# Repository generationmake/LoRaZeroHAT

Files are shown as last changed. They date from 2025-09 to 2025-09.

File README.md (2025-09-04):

# LoRaZeroHAT
Raspberry Pi HAT with Ai-Thinker Ra-01 or Ra-02 LoRa module connected via SPI and an u-blox NEO-6M or NEO-M8N GNSS receiver connected to serial.

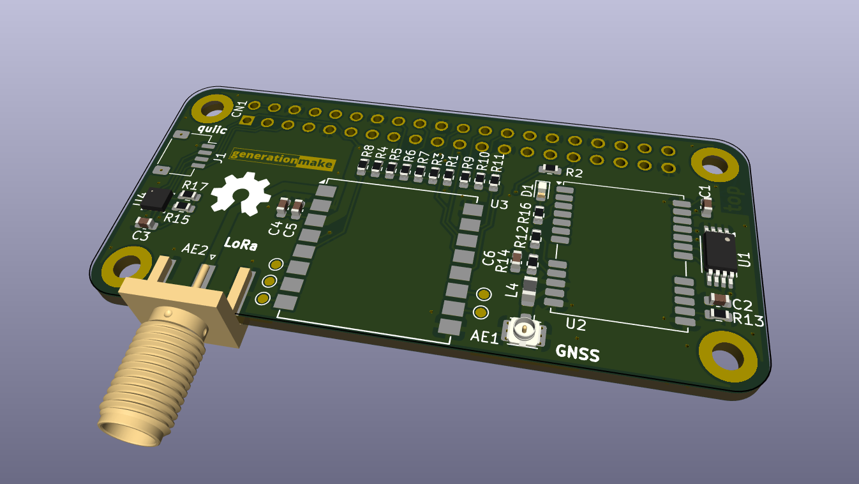
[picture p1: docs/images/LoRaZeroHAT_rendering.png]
LoRaZeroHAT rendering


## PCB

### Top

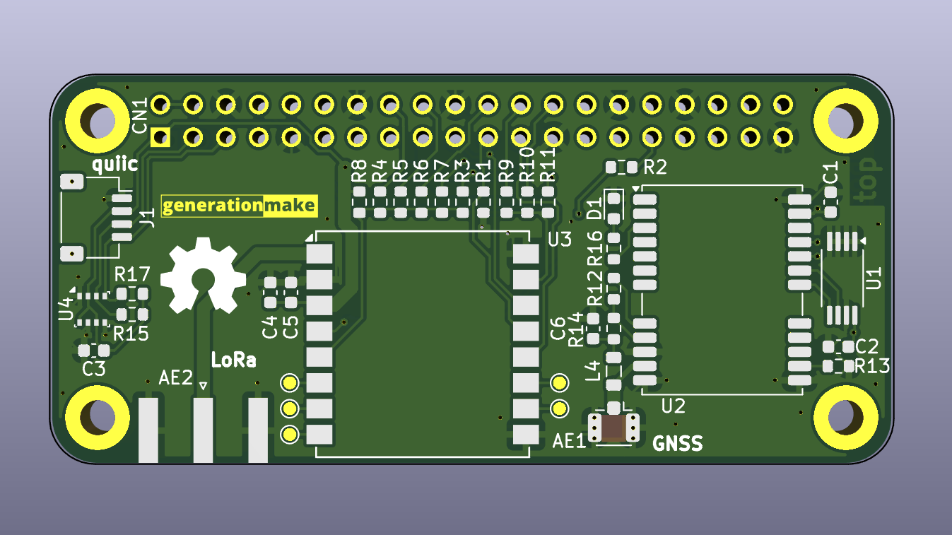
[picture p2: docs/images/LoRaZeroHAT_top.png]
LoRaZeroHAT PCB top


### Bottom

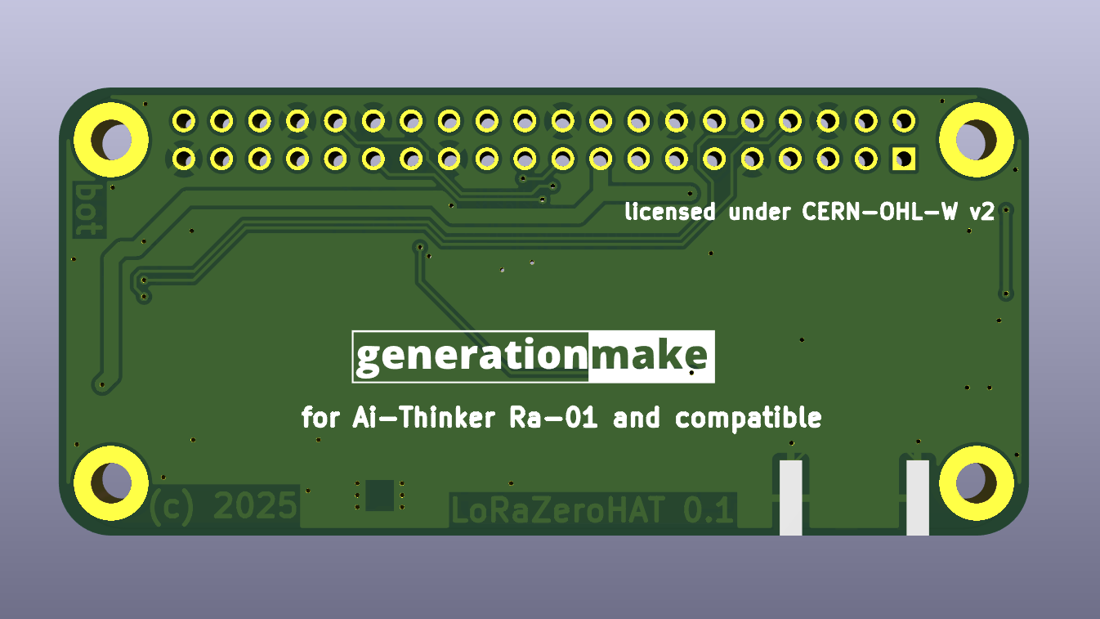
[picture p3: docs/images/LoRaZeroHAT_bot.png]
LoRaZeroHAT PCB bot


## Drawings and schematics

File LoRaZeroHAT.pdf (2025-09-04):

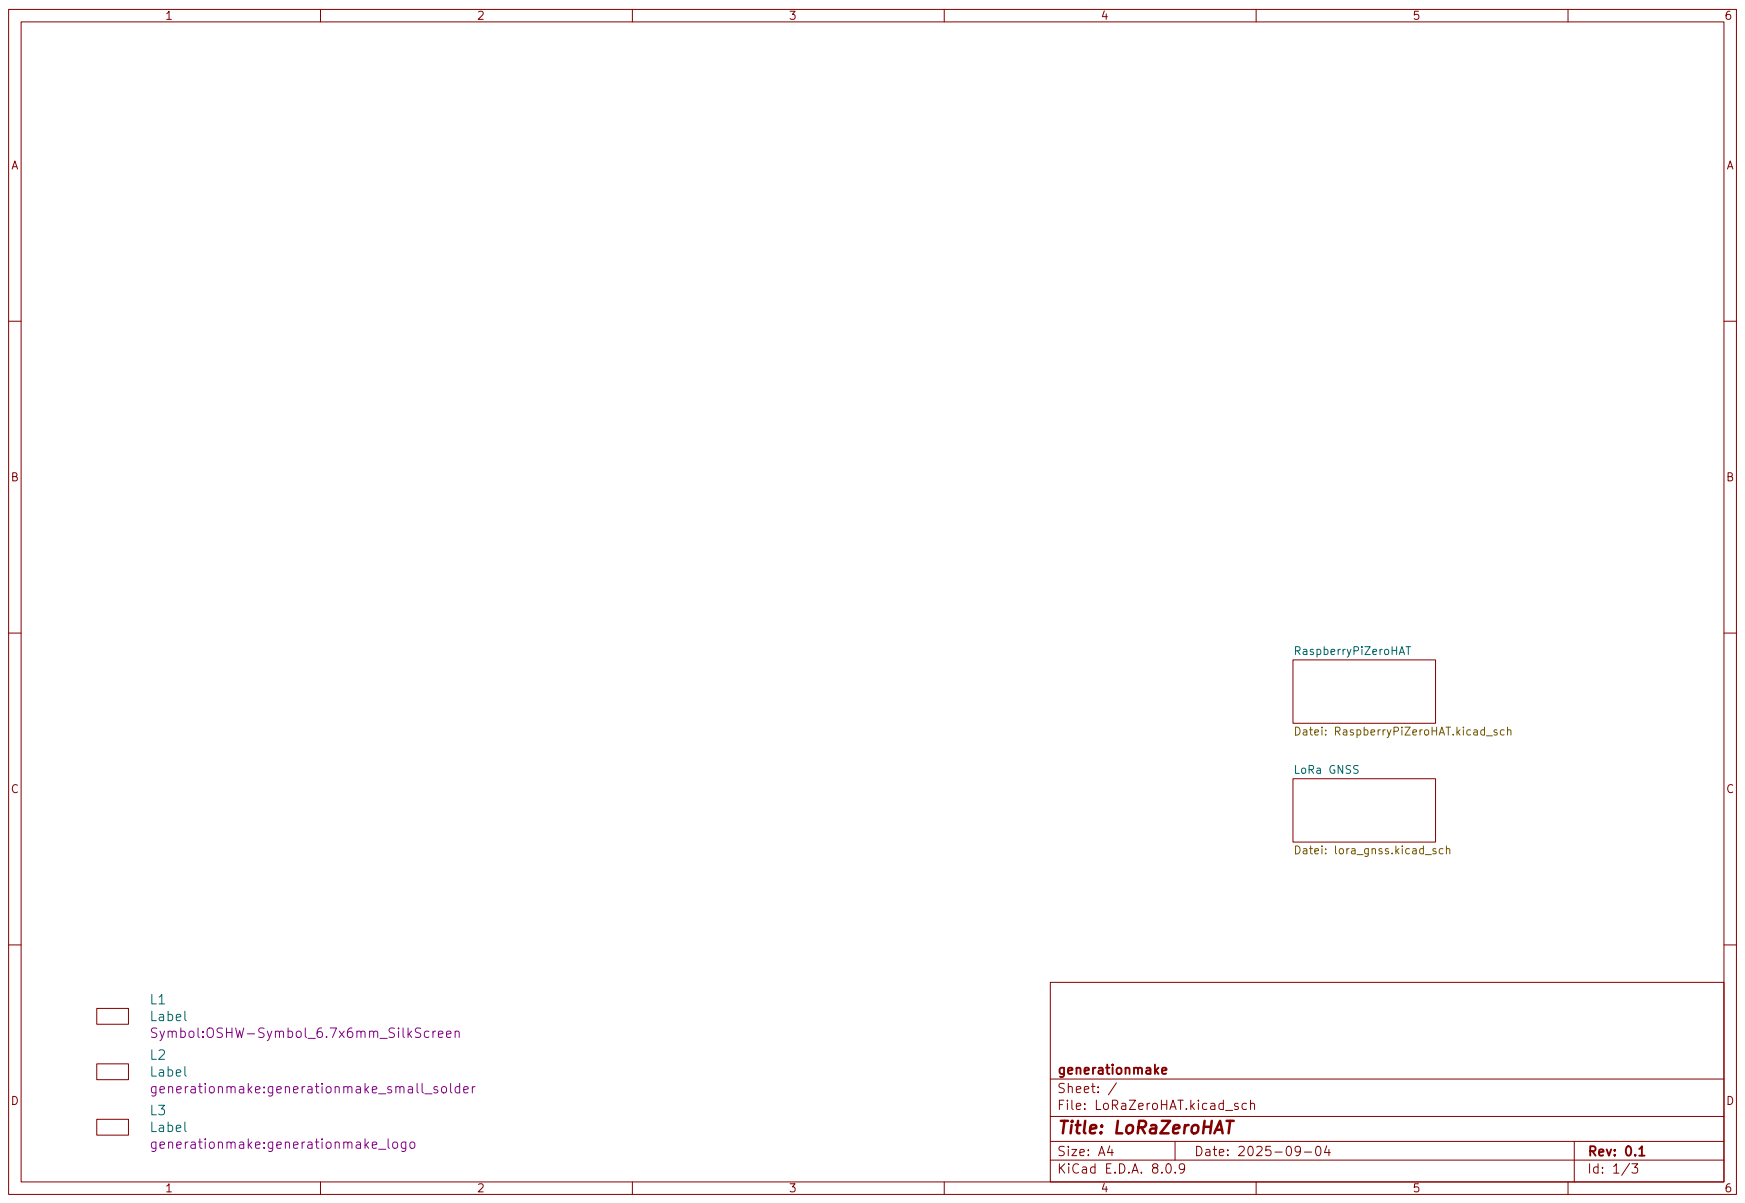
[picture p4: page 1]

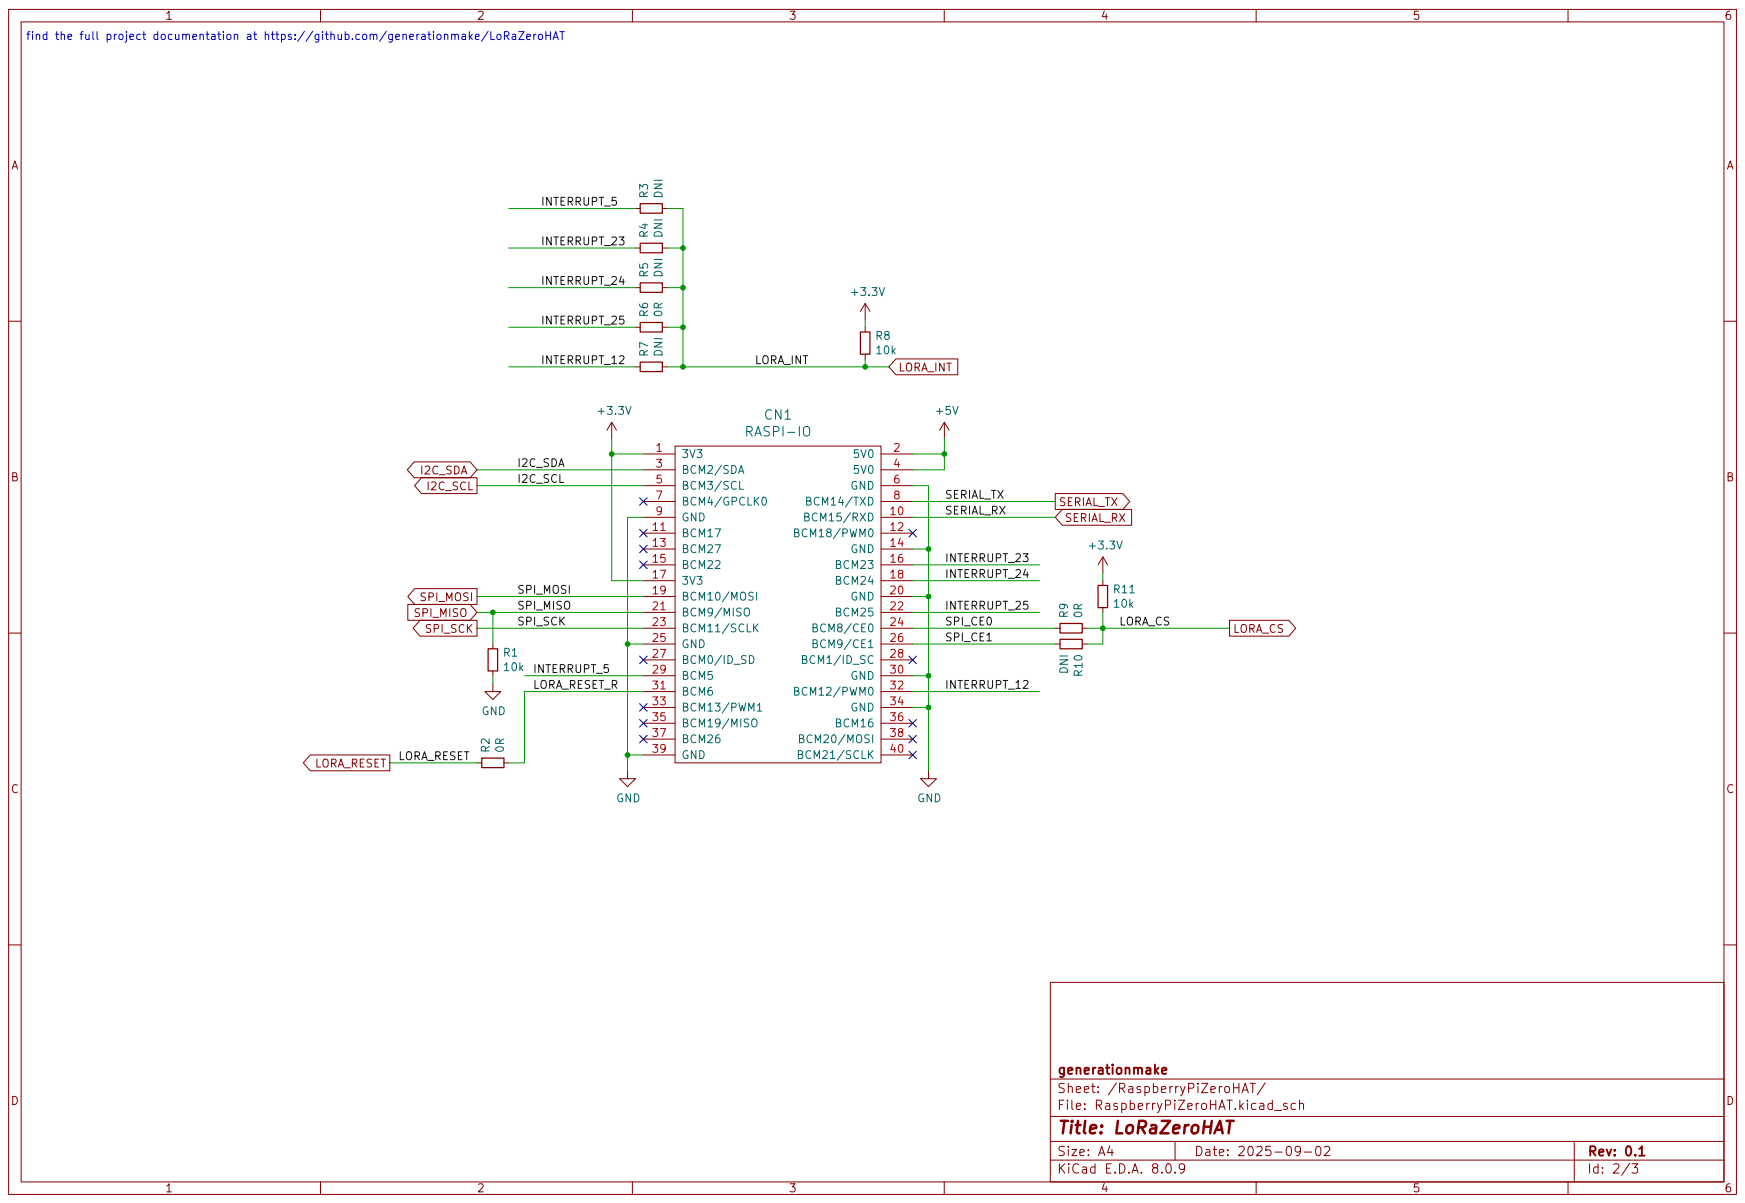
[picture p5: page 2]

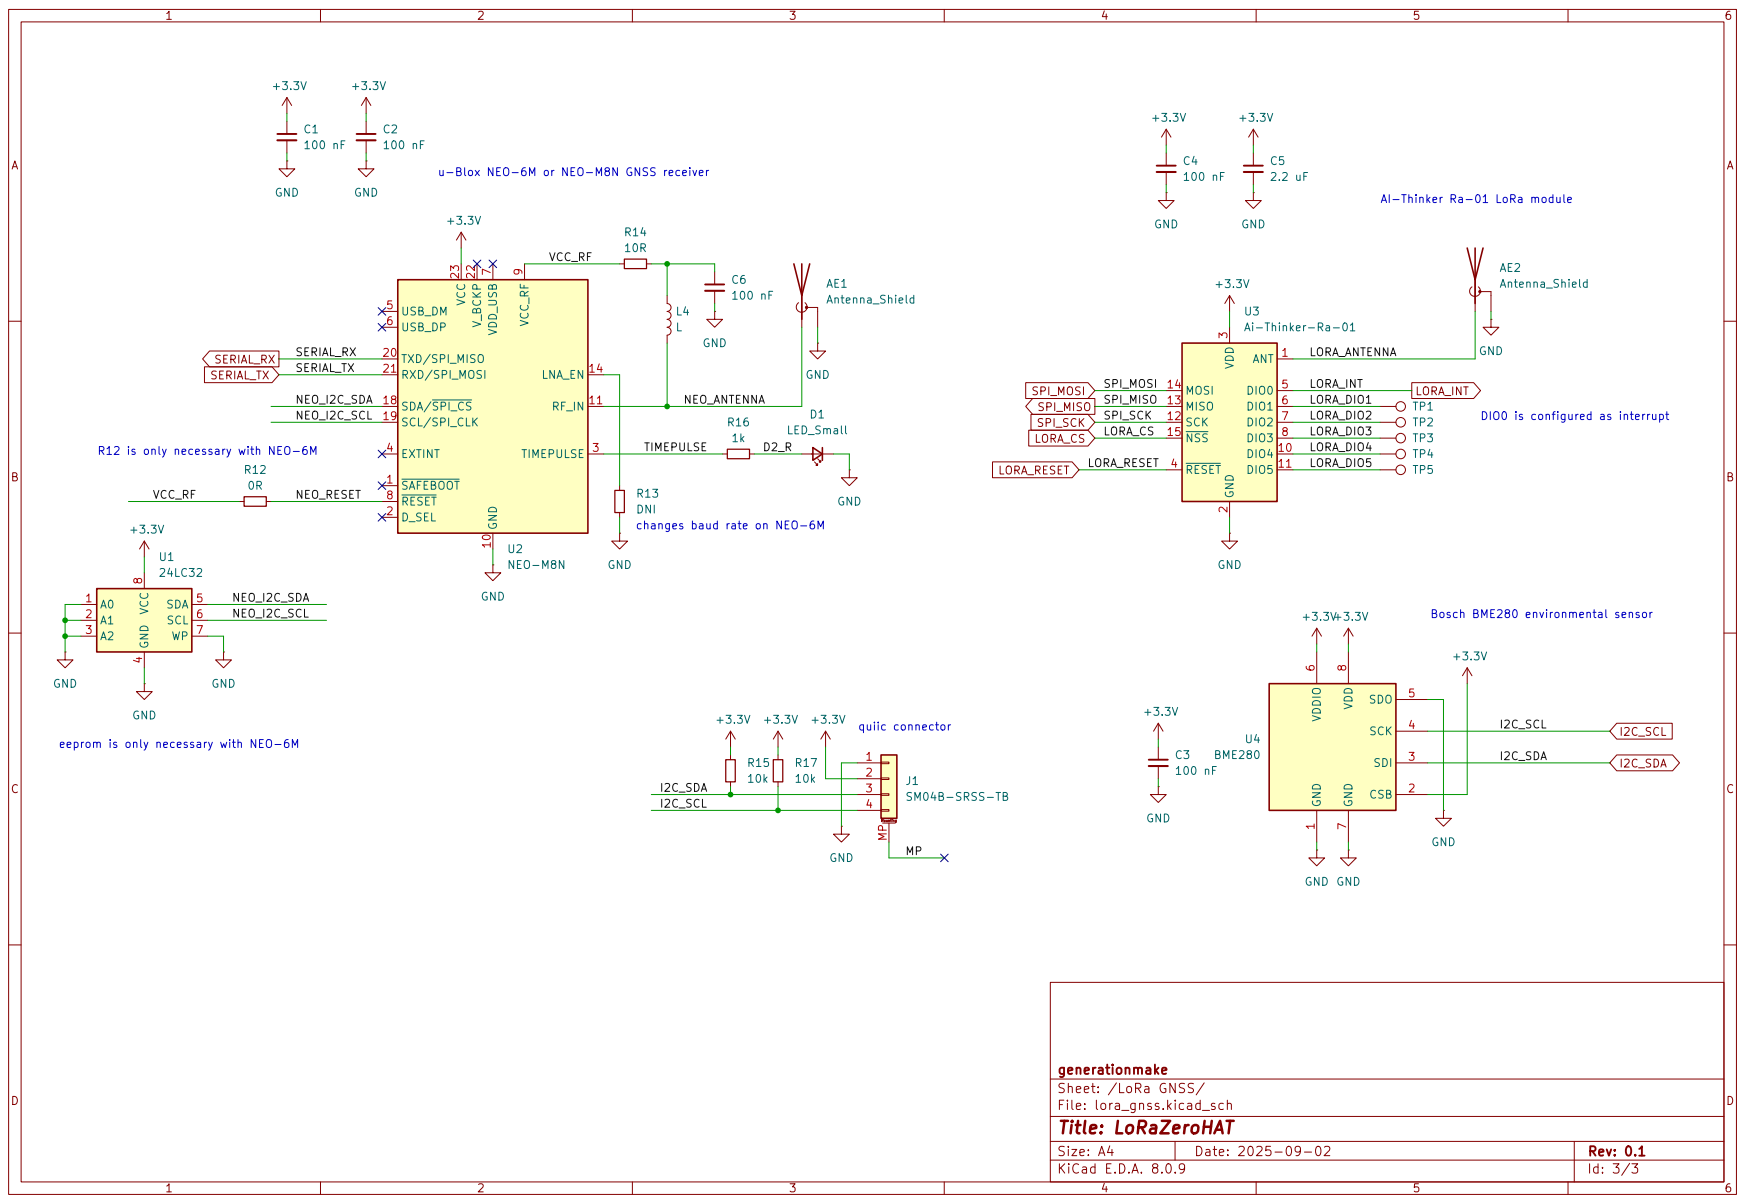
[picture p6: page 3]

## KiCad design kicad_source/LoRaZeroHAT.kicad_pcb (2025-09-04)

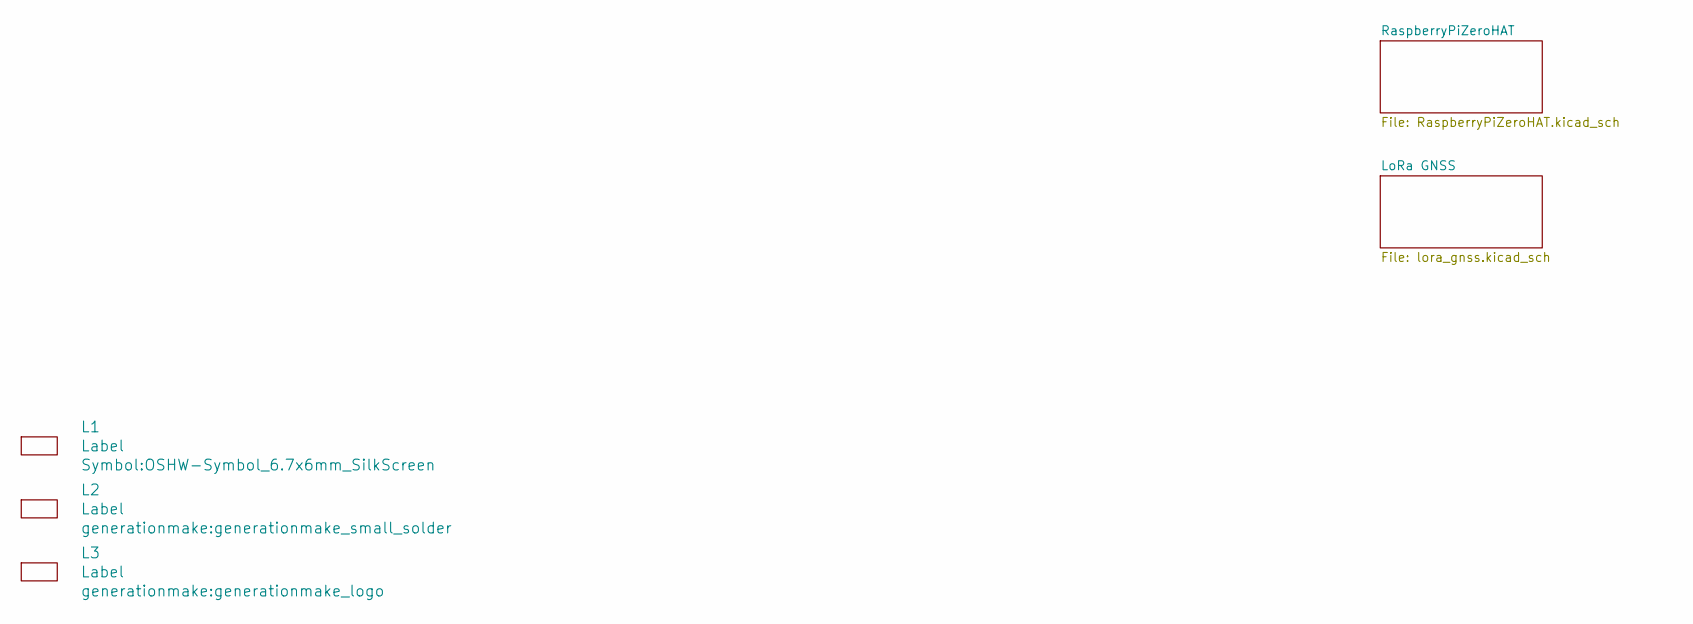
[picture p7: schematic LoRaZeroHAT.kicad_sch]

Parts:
L1: Label; OSHW-Symbol_6.7x6mm_SilkScreen
L2: Label; generationmake_small_solder
L3: Label; generationmake_logo

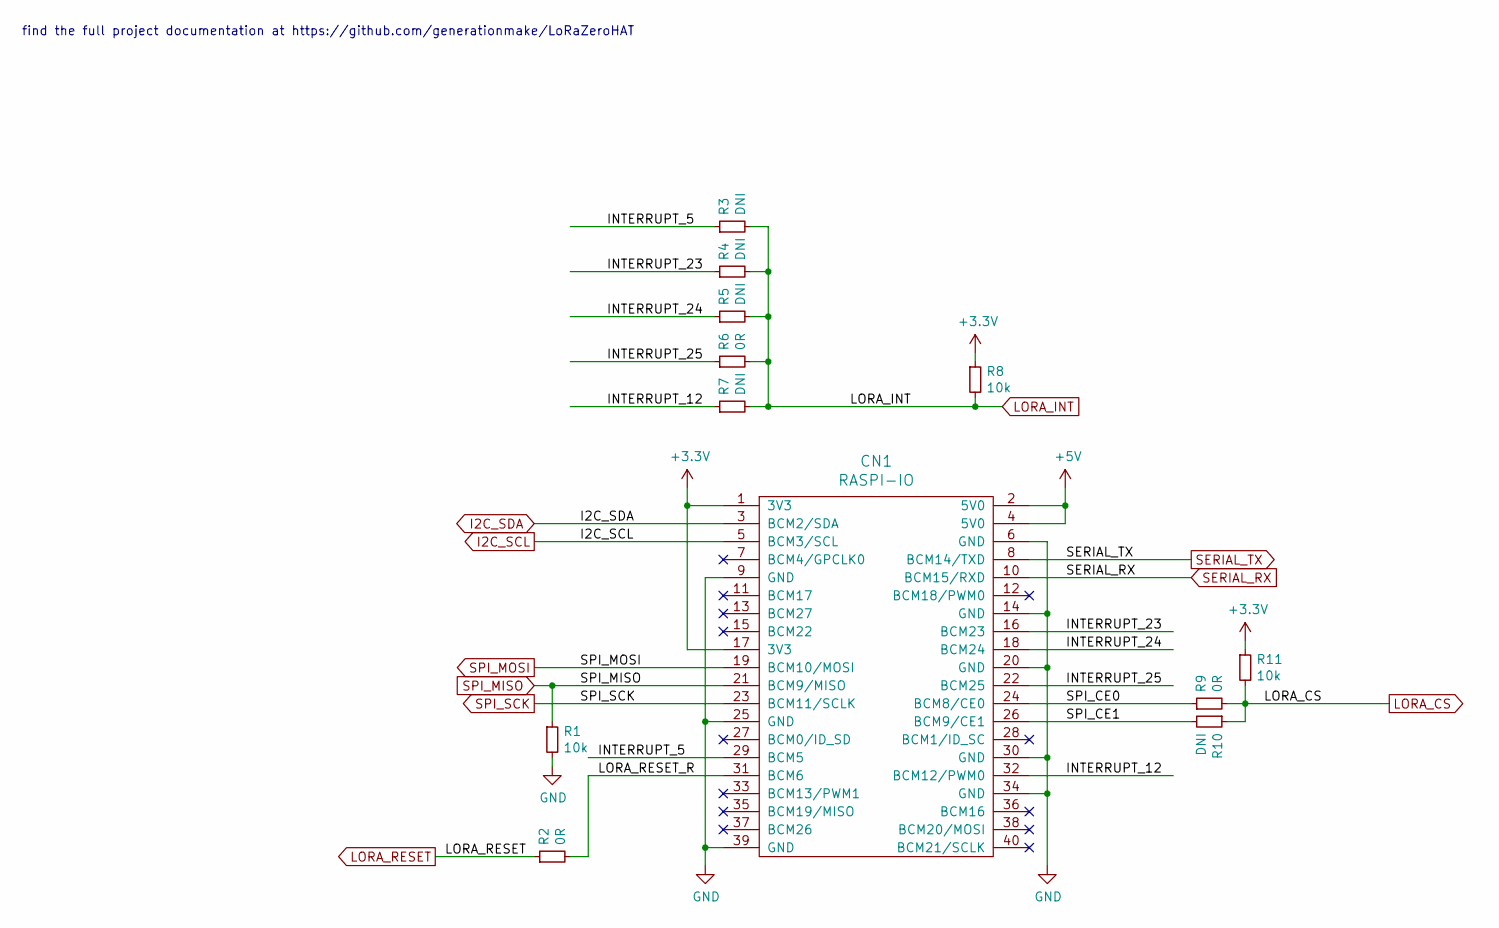
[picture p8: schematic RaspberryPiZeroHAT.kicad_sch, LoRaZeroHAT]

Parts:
CN1: RASPI-IO; RASPI_ZERO_HAT_EDGE; LCSC C50982
R1, R8, R11: 10k; R_0603_1608Metric; LCSC C25804
R2, R6, R9: 0R; R_0603_1608Metric; LCSC C2889381
R3, R4, R5, R7, R10: DNI; R_0603_1608Metric

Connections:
+3.3V: CN1.1 (3V3), CN1.17 (3V3), R8.1, R11.1; also elsewhere on the board
+5V: CN1.2 (5V0), CN1.4 (5V0)
/RaspberryPiZeroHAT/INTERRUPT_5: CN1.29 (BCM5), R3.1
/RaspberryPiZeroHAT/INTERRUPT_12: CN1.32 (BCM12/PWM0), R7.1
/RaspberryPiZeroHAT/INTERRUPT_23: CN1.16 (BCM23), R4.1
/RaspberryPiZeroHAT/INTERRUPT_24: CN1.18 (BCM24), R5.1
/RaspberryPiZeroHAT/INTERRUPT_25: CN1.22 (BCM25), R6.1
/RaspberryPiZeroHAT/LORA_RESET_R: CN1.31 (BCM6), R2.2
/RaspberryPiZeroHAT/SPI_CE0: CN1.24 (BCM8/CE0), R9.1
/RaspberryPiZeroHAT/SPI_CE1: CN1.26 (BCM9/CE1), R10.2
GND: CN1.6 (GND), CN1.9 (GND), CN1.14 (GND), CN1.20 (GND), CN1.25 (GND), CN1.30 (GND), CN1.34 (GND), CN1.39 (GND), R1.2; also elsewhere on the board
I2C_SCL: CN1.5 (BCM3/SCL); also elsewhere on the board
I2C_SDA: CN1.3 (BCM2/SDA); also elsewhere on the board
LORA_CS: R9.2, R10.1, R11.2; also elsewhere on the board
LORA_INT: R3.2, R4.2, R5.2, R6.2, R7.2, R8.2; also elsewhere on the board
LORA_RESET: R2.1; also elsewhere on the board
SERIAL_RX: CN1.10 (BCM15/RXD); also elsewhere on the board
SERIAL_TX: CN1.8 (BCM14/TXD); also elsewhere on the board
SPI_MISO: CN1.21 (BCM9/MISO), R1.1; also elsewhere on the board
SPI_MOSI: CN1.19 (BCM10/MOSI); also elsewhere on the board
SPI_SCK: CN1.23 (BCM11/SCLK); also elsewhere on the board

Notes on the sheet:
find the full project documentation at https://github.com/generationmake/LoRaZeroHAT

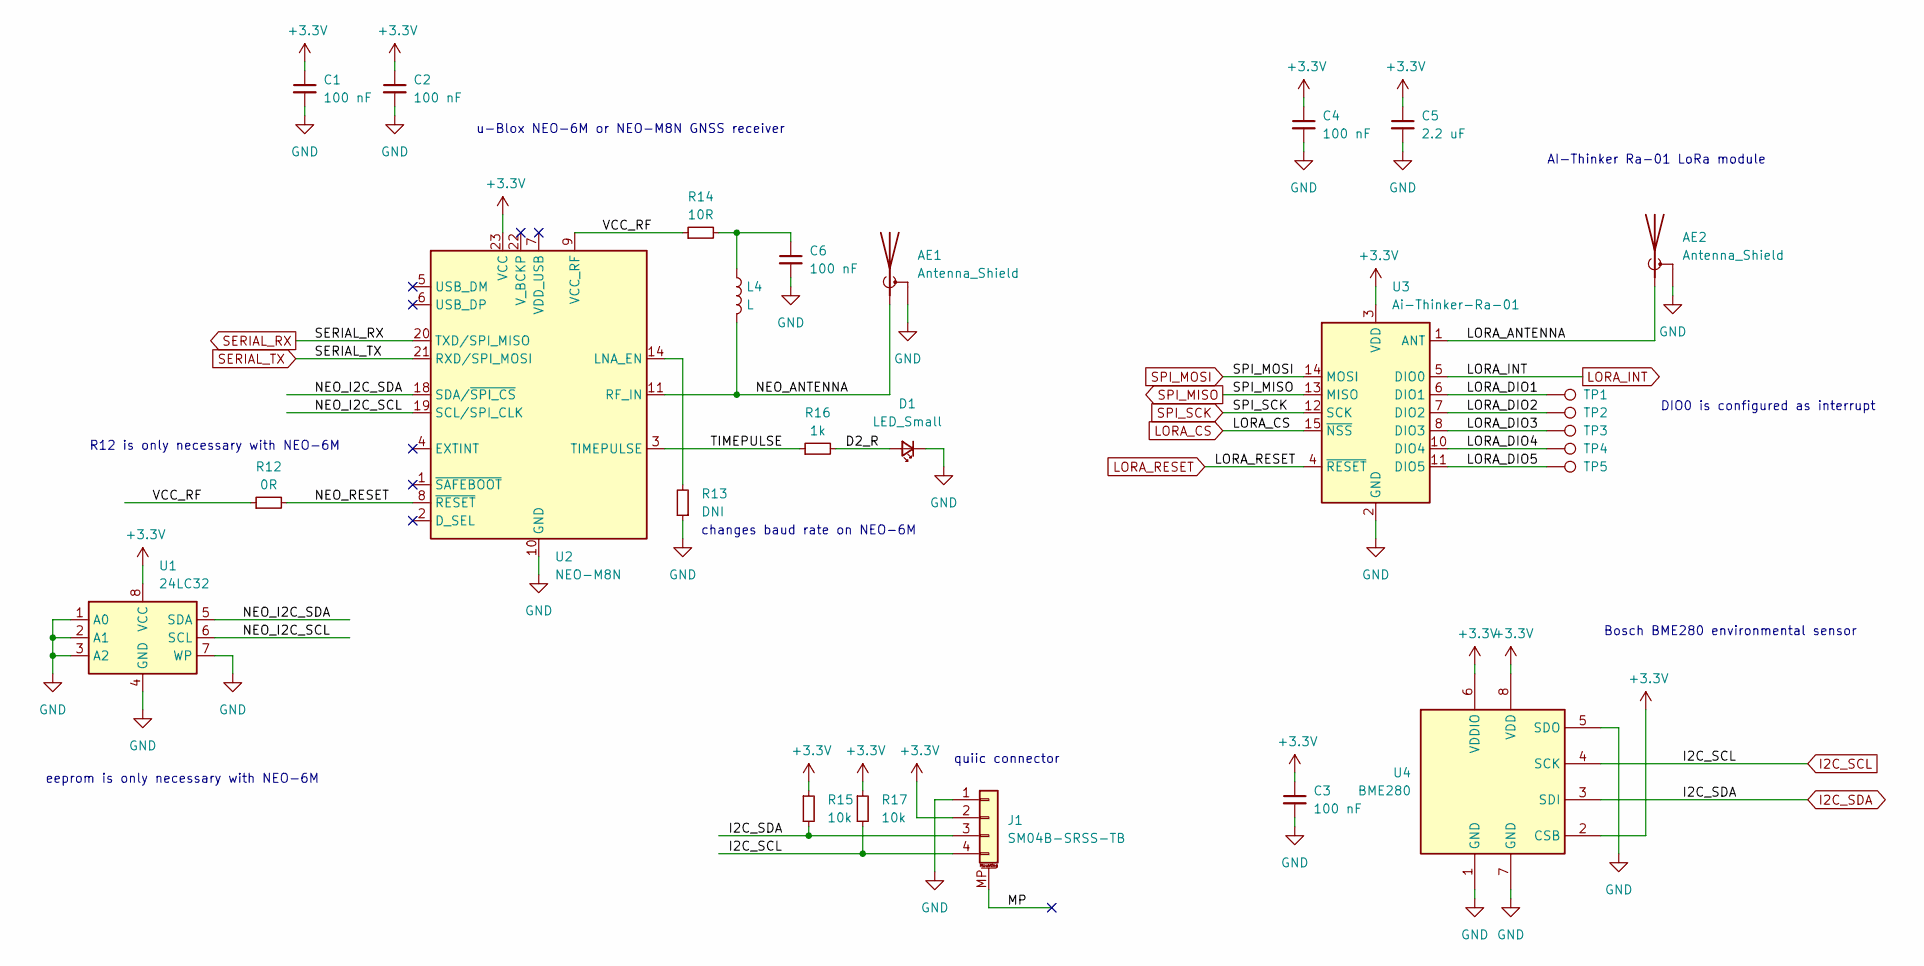
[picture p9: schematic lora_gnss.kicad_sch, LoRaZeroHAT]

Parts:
AE1: Antenna_Shield; U.FL_Hirose_U.FL-R-SMT-1_Vertical
AE2: Antenna_Shield; SMA_Amphenol_132289_EdgeMount
C1, C2, C3, C4, C6: 100 nF; C_0603_1608Metric
C5: 2.2 uF; C_0603_1608Metric
D1: LED_Small; LED_0603_1608Metric
J1: SM04B-SRSS-TB; JST_SH_SM04B-SRSS-TB_1x04-1MP_P1.00mm_Horizontal
L4: L; L_0805_2012Metric
R12: 0R; R_0603_1608Metric
R13: DNI; R_0603_1608Metric
R14: 10R; R_0603_1608Metric
R15, R17: 10k; R_0603_1608Metric
R16: 1k; R_0603_1608Metric
TP1, TP2, TP3, TP4, TP5: TestPoint; TestPoint_Pad_D1.0mm
U1: 24LC32; TSSOP-8_4.4x3mm_P0.65mm
U2: NEO-M8N; ublox_NEO
U3: Ai-Thinker-Ra-01; Ai-Thinker-Ra-01-LoRa
U4: BME280; Bosch_LGA-8_2.5x2.5mm_P0.65mm_ClockwisePinNumbering

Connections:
+3.3V: C1.1, C2.1, C3.1, C4.1, C5.1, J1.2, R15.1, R17.1, U1.8 (VCC), U2.23 (VCC), U3.3 (VDD), U4.2 (CSB), U4.6 (VDDIO), U4.8 (VDD); also elsewhere on the board
/LoRa GNSS/D2_R: D1.2 (A), R16.2
/LoRa GNSS/LORA_ANTENNA: AE2.1 (A), U3.1 (ANT)
/LoRa GNSS/LORA_DIO1: TP1.1, U3.6 (DIO1)
/LoRa GNSS/LORA_DIO2: TP2.1, U3.7 (DIO2)
/LoRa GNSS/LORA_DIO3: TP3.1, U3.8 (DIO3)
/LoRa GNSS/LORA_DIO4: TP4.1, U3.10 (DIO4)
/LoRa GNSS/LORA_DIO5: TP5.1, U3.11 (DIO5)
/LoRa GNSS/MP: J1.MP (MountPin)
/LoRa GNSS/MP_1: J1.MP (MountPin)
/LoRa GNSS/NEO_ANTENNA: AE1.1 (A), L4.2, U2.11 (RF_IN)
/LoRa GNSS/NEO_I2C_SCL: U1.6 (SCL), U2.19 (SCL/SPI_CLK)
/LoRa GNSS/NEO_I2C_SDA: U1.5 (SDA), U2.18 (SDA/~SPI_CS)
/LoRa GNSS/NEO_RESET: R12.2, U2.8 (~RESET)
/LoRa GNSS/TIMEPULSE: R16.1, U2.3 (TIMEPULSE)
/LoRa GNSS/VCC_RF: R12.1, R14.1, U2.9 (VCC_RF)
GND: AE1.2 (Shield), AE2.2 (Shield), C1.2, C2.2, C3.2, C4.2, C5.2, C6.2, D1.1 (K), J1.1, R13.1, U1.1 (A0), U1.2 (A1), U1.3 (A2), U1.4 (GND), U1.7 (WP), U2.10 (GND), U2.12 (GND), U2.13 (GND), U2.24 (GND), U3.2 (GND), U3.9 (GND), U3.16 (GND), U4.1 (GND), U4.5 (SDO), U4.7 (GND); also elsewhere on the board
I2C_SCL: J1.4, R17.2, U4.4 (SCK); also elsewhere on the board
I2C_SDA: J1.3, R15.2, U4.3 (SDI); also elsewhere on the board
LORA_CS: U3.15 (~NSS); also elsewhere on the board
LORA_INT: U3.5 (DIO0); also elsewhere on the board
LORA_RESET: U3.4 (~RESET); also elsewhere on the board
unnamed: C6.1, L4.1, R14.2
unnamed: R13.2, U2.14 (LNA_EN)
SERIAL_RX: U2.20 (TXD/SPI_MISO); also elsewhere on the board
SERIAL_TX: U2.21 (RXD/SPI_MOSI); also elsewhere on the board
SPI_MISO: U3.13 (MISO); also elsewhere on the board
SPI_MOSI: U3.14 (MOSI); also elsewhere on the board
SPI_SCK: U3.12 (SCK); also elsewhere on the board

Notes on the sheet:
R12 is only necessary with NEO-6M
eeprom is only necessary with NEO-6M
changes baud rate on NEO-6M
u-Blox NEO-6M or NEO-M8N GNSS receiver
quiic connector
DIO0 is configured as interrupt
Bosch BME280 environmental sensor
AI-Thinker Ra-01 LoRa module

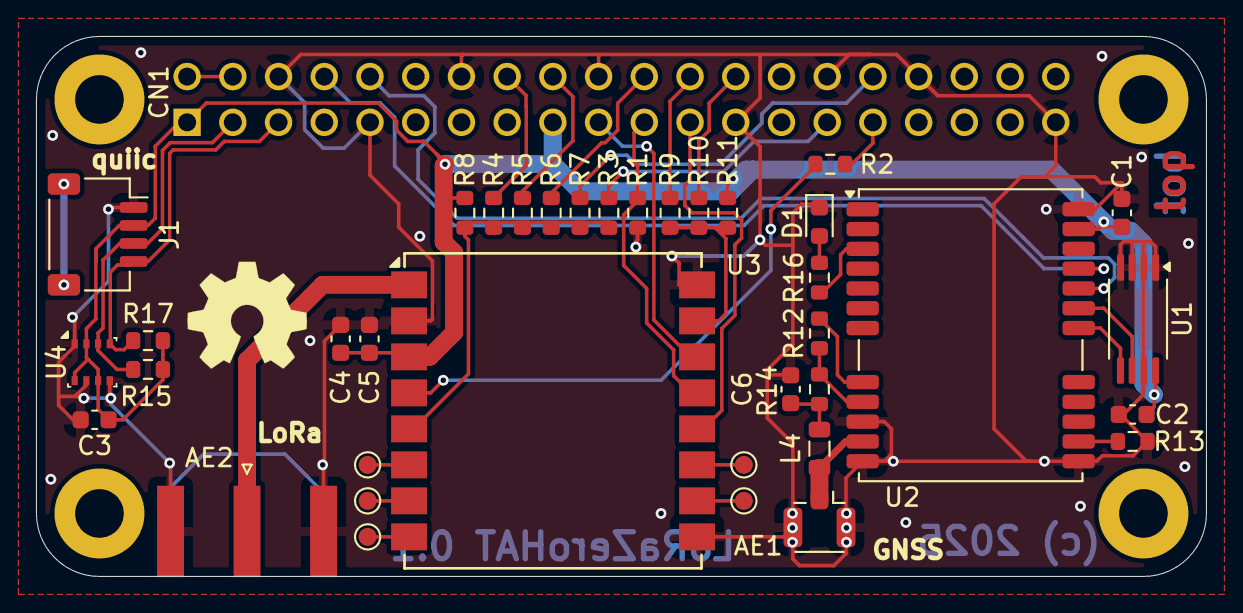
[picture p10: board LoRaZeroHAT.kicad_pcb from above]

Board: 2 copper layers, 65.0 x 30.0 mm, 41 parts (1 on the bottom side), 36 nets.

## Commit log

2025-09-02 copied kicad project together
    [LoRaZeroHAT.kicad_pcb, LoRaZeroHAT.kicad_sch, RP2040.kicad_sch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]
2025-09-02 glued project together
    [LoRaZeroHAT.kicad_sch, RP2040.kicad_sch, RaspberryPiZeroHAT.kicad_sch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]
2025-09-02 connected schematic to layout
    [LoRaZeroHAT.kicad_pcb, LoRaZeroHAT.kicad_sch, RaspberryPiZeroHAT.kicad_sch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]
2025-09-02 made first connections
    [LoRaZeroHAT.kicad_pcb, LoRaZeroHAT.kicad_sch, RaspberryPiZeroHAT.kicad_sch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]
2025-09-02 updated layout
    [LoRaZeroHAT.kicad_pcb, LoRaZeroHAT.kicad_sch, RaspberryPiZeroHAT.kicad_sch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]
2025-09-02 schaltplan neu annotiert
    [LoRaZeroHAT.kicad_pcb, LoRaZeroHAT.kicad_sch, RaspberryPiZeroHAT.kicad_sch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]
2025-09-02 updated DRC
    [LoRaZeroHAT.kicad_pcb]
2025-09-03 updated label
    [LoRaZeroHAT.kicad_pcb]
2025-09-04 added capacitor C6 on u-blox VCC_RF
    [LoRaZeroHAT.kicad_pcb, LoRaZeroHAT.kicad_sch, lora_gnss.kicad_sch]
2025-09-04 added schematic pdf

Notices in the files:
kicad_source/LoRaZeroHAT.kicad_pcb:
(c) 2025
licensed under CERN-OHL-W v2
